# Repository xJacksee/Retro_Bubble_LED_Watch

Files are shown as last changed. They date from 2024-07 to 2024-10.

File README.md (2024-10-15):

# Retro Bubble LED Watch
Retro Bubble LED Watch is a project dedicated to infamous HP's bubble LED seven segment displays produced around 1970s. The goal of this project is to create fully functional retro watch from scratch (including code) based around modern components while the aforementioned display being the centerpiece.

## Project's goal
Retro Bubble LED Watch is a project dedicated to infamus HP's bubble LED seven segment displays produced around 1970s. The goal of this project is to create fully functional retro watch from scratch (including code) based around modern components while the afordmentioned display being the centerpiece.

## Components
The circuit features ATMega328PB microcontroller fulfilling the role as the display multiplexer and I2C communicator with RTC module. For the RTC IC a popular DS1337 has been chosen due it's low standby power, wide supplay voltage range and low price point. Along with this IC comes an external precision quartz crystal designed for digital watches. Due to space limitations a standard 3V CR2032 lithium coin battery supplies power to the circuit. The capacity as well as the footprint of this power source is quite large and thus the rough estimated lifetime of single cell might be as long as 2,5 years while normal use.

## Features
- Display time with precision to tenths of seconds
- Date and numbered day of the week (1 - monday etc.) display
- Temperature measurement by uC's built-in sensor (requires individual calibration)
- 2 independent alarms
- Optional external buzzer activated on alarm trigger
- SPI pins accesable for easy reprogramming
- 2 buttons for activating display/changing modes and time/date/alarm setting

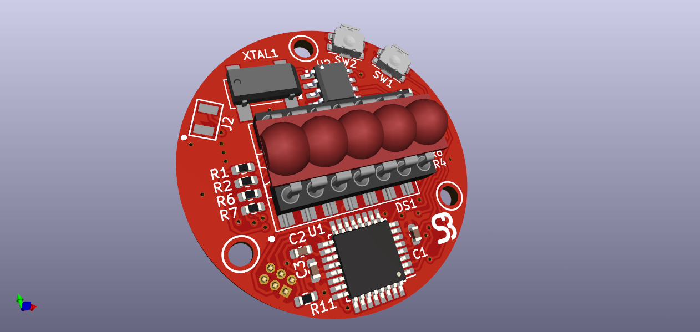
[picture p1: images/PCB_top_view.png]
PCB Top View

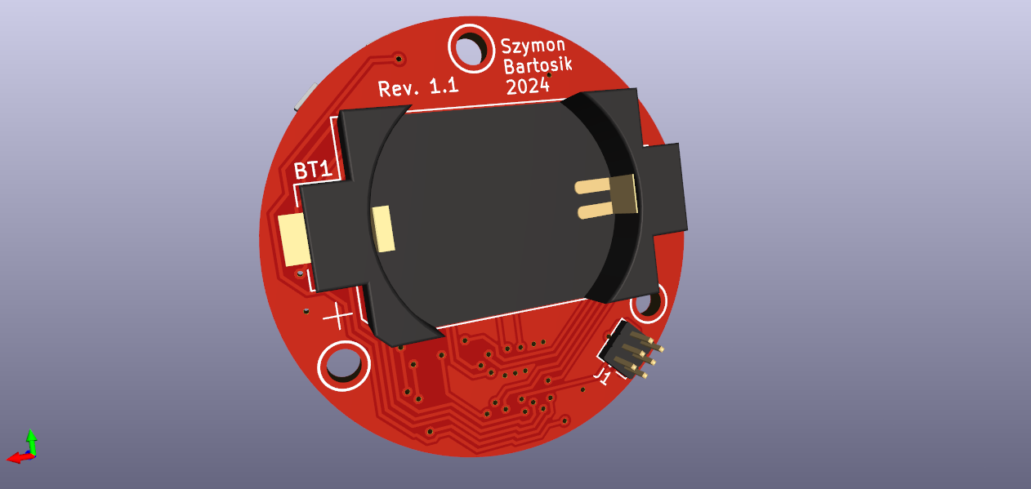
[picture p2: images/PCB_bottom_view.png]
PCB Bottom View


## Dependencies
The programme has been written in Arduino using only Wire library. To upload the code it is nessesary to install and add Mini-Core library to Arduino IDE. The fuse bits settings for ATmega328PB have to be left at factory default (including clock - internal 8MHz RC colock have been used) according to official Microchip datasheet.

## Temperature sensor calibration
Please refer to to ATmega328PB's datasheet section 28.8. "Temperature Measurement" or AVR122 application note. Every MCU requires individual calibration. In this project, a single point calibration method was used. The offset value can be tuned in source code by changing the value of "T_OFFSET" definition.

## External buzzer
Due to space limitations, an alarm buzzer couldn't be fitted on the PCB. Solder pads J2 provide a connection to the PE0 pin of MCU that turns on periodacly during the alarm. External piezoelectric disc can be connected to these pads and fitted onto the internal surface of the lid. The buzzer must not consume more than 40mA otherwise MCU can be damaged. 

## Case
The case is designed to be 3D printed using any material. Supports are nessesary.

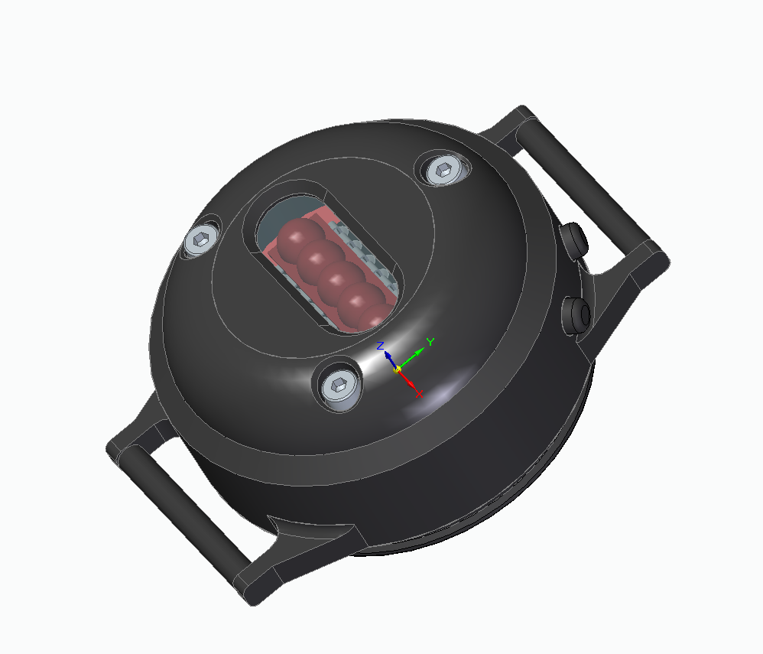
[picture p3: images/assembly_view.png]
Assembly

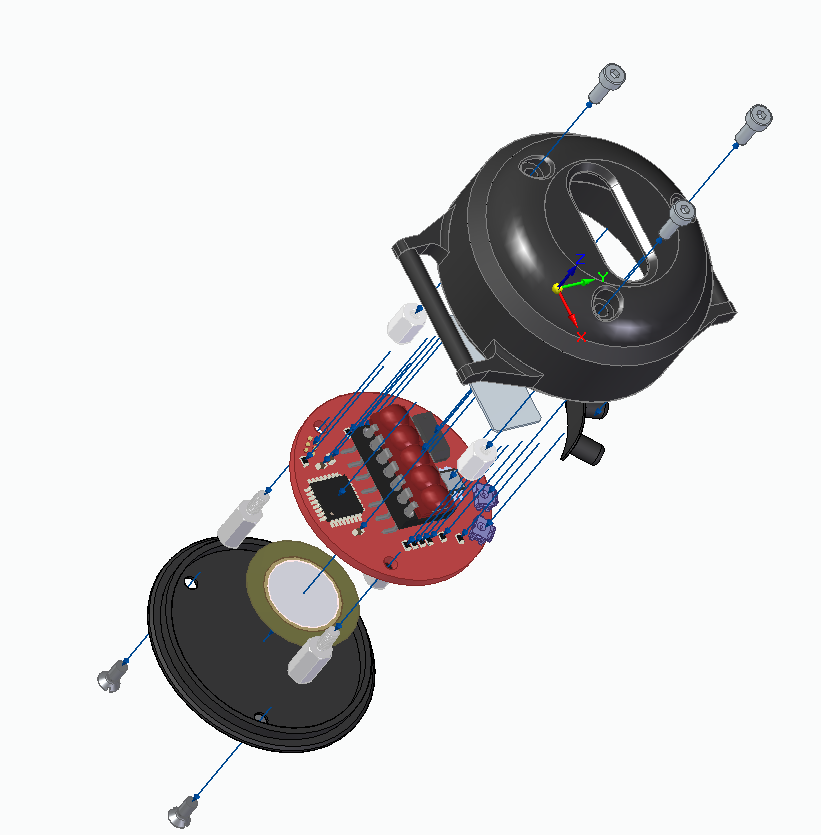
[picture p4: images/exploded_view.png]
Exploded View


## Battery life and current consumption
The CR2032 battery has the capacity to power the circuit for over 2 years but the accurate battery life is dependant on frequency of turing on the display which can consume up to 35mA in peak. This loads the battery and the voltage drop can couse the uC to shutdown when battery is drained. While in sleep the circuit consumes, according to manufacturers' datasheets maximum of arund 5uA in worst case scenario.

## Authors
Szymon Bartosik

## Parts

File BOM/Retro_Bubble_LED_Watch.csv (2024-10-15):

Source: | C:\Users\Szymon\Documents\Projects_Repository\Retro_Bubble_LED_Watch\kicad\Retro_Bubble_LED_Watch\Retro_Bubble_LED_Watch.kicad_sch
Date: | 15/10/2024 12:57:53
Tool: | Eeschema 7.0.10
Generator: | C:\Program Files\KiCad\7.0\bin\scripting\plugins/bom_csv_grouped_by_value.py
Component Count: | 23
Collated Components:
Item | Qty | Reference(s) | Value | LibPart | Footprint | Datasheet | DNP | Manufacturer | Model | Socket | Socket
1 | 1 | BT1 | 3V | Device:Battery_Cell | Battery:BatteryHolder_Keystone_1060_1x2032 | ~ |  | PANASONIC | CR2032/BN |  | KEYSTONE 1060
2 | 3 | C1, C2, C3 | 100n | Device:C | Capacitor_SMD:C_0603_1608Metric | ~ |  | SAMSUNG | CL10B104KA8NFNC
3 | 1 | DS1 | 5082-7415 | 5082-7415:5082-7415 | Package_DIP:DIP-14_W8.89mm_SMDSocket_LongPads |  |  | HP |  | CONNFLY DS1001-02-14N13
4 | 1 | J1 | 20021111-00006T4LF | Connector_Generic:Conn_02x03_Counter_Clockwise | Connector_PinHeader_1.27mm:PinHeader_2x03_P1.27mm_Vertical | ~ |  | AMPHENOL COMMUNICATIONS SOLUTIONS
5 | 1 | J2 | Pad Connector | Connector_Generic:Conn_01x02 | footprints:Pad_Conn_2x1_2x1mm_2.54mm | ~
6 | 8 | R1, R2, R3, R4, R5, R6, R7, R8 | 330R | Device:R | Resistor_SMD:R_0603_1608Metric | ~ |  | PANASONIC | ERJ3EKF3300V
7 | 3 | R9, R10, R11 | 10k | Device:R | Resistor_SMD:R_0603_1608Metric | ~ |  | PANASONIC | ERJ3EKF1002V
8 | 2 | SW1, SW2 | KMS231G | Switch:SW_Push | Button_Switch_SMD:SW_SPST_CK_KMS2xxG | ~ |  | C&K | KMS231GLFS
9 | 1 | U1 | ATmega328PB-A | MCU_Microchip_ATmega:ATmega328PB-A | Package_QFP:TQFP-32_7x7mm_P0.8mm | http://ww1.microchip.com/downloads/en/DeviceDoc/40001906C.pdf |  | MICROCHIP
10 | 1 | U2 | DS1337S+ | DS1337S+:DS1337S+ | footprints:SOIC127P600X175-8N |  |  | MAXIM INTEGRATED
11 | 1 | XTAL1 | LFXTAL016178Reel | LFXTAL016178Reel:LFXTAL016178Reel | footprints:LFXTAL016178Reel |  |  | IQD FREQUENCY PRODUCTS

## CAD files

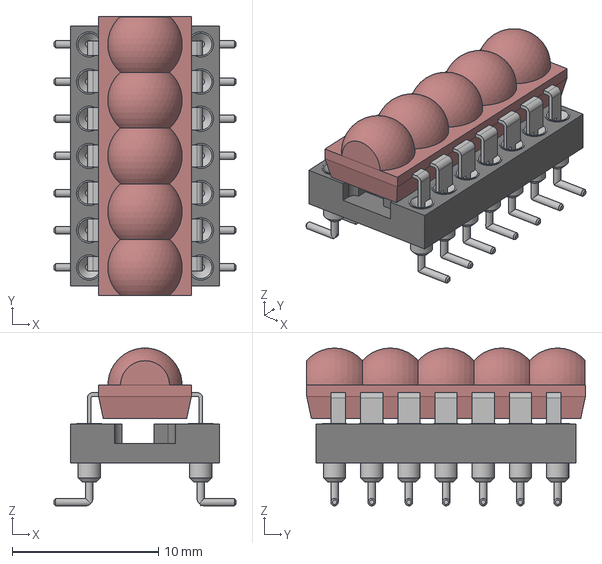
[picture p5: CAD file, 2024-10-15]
models/step/HP5082-7415_with_SMD_Socket_assembly.stp
12.4 x 19.1 x 10.8 mm

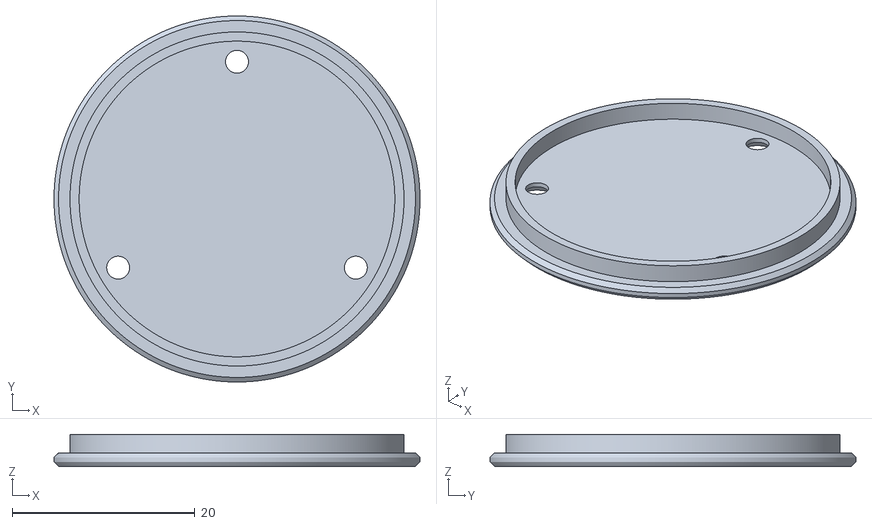
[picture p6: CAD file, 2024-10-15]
models/stl/lid.stl
40.0 x 40.0 x 3.50

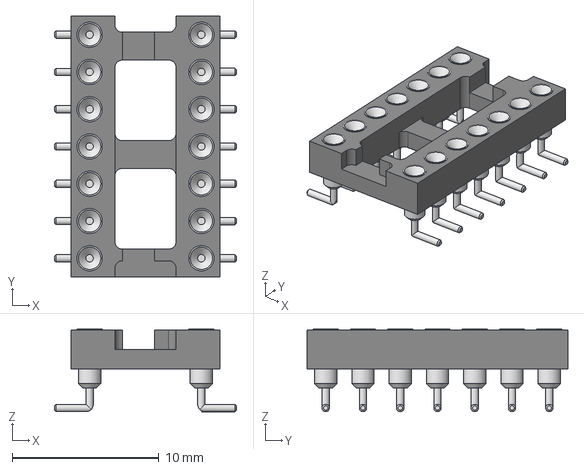
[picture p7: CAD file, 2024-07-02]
models/step/DIP-14_W7.62mm_SMD_Socket.stp
12.4 x 17.8 x 5.63 mm

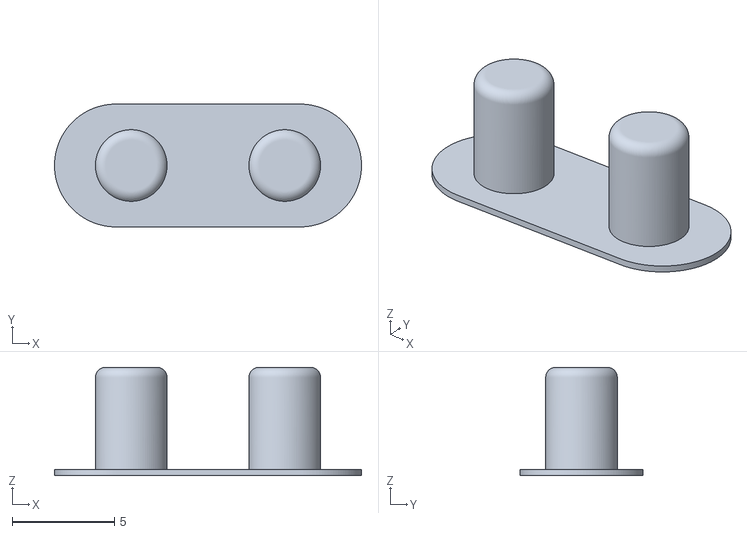
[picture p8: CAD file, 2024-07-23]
models/stl/buttons.stl
15.0 x 6.00 x 5.30

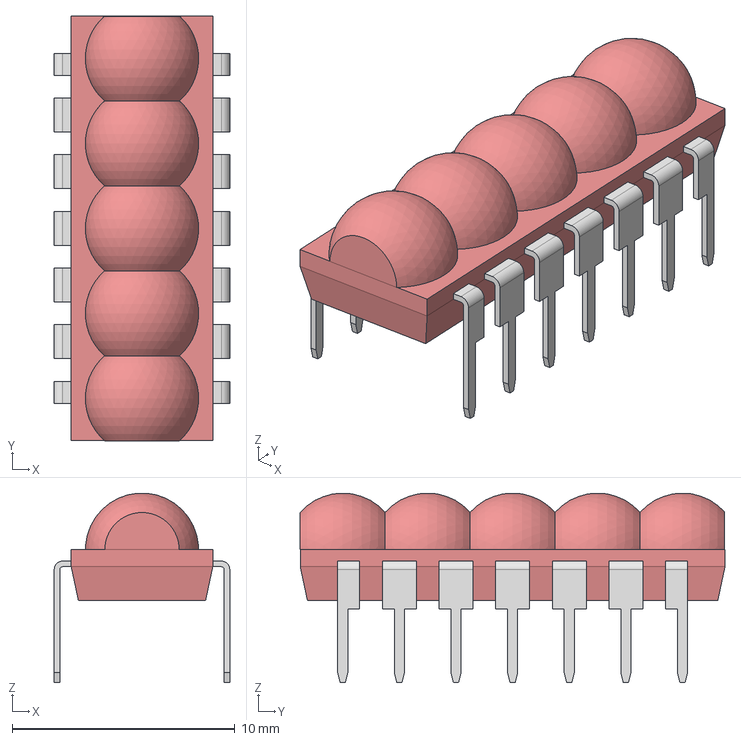
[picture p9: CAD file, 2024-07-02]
models/step/HP5082-7415.stp
7.87 x 19.1 x 8.50 mm

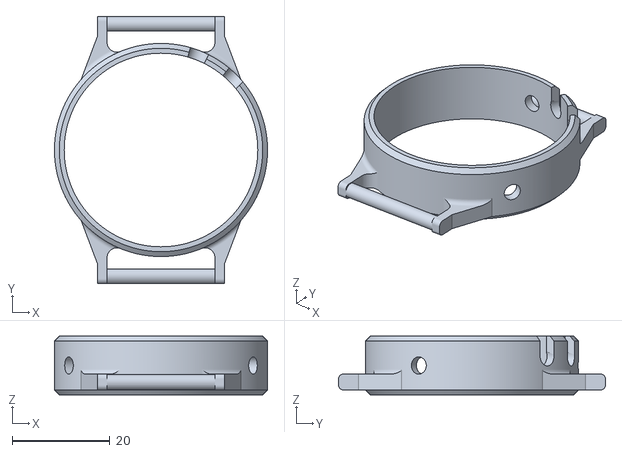
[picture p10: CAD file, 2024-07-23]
models/stl/strap_holder.stl
43.5 x 54.5 x 12.0

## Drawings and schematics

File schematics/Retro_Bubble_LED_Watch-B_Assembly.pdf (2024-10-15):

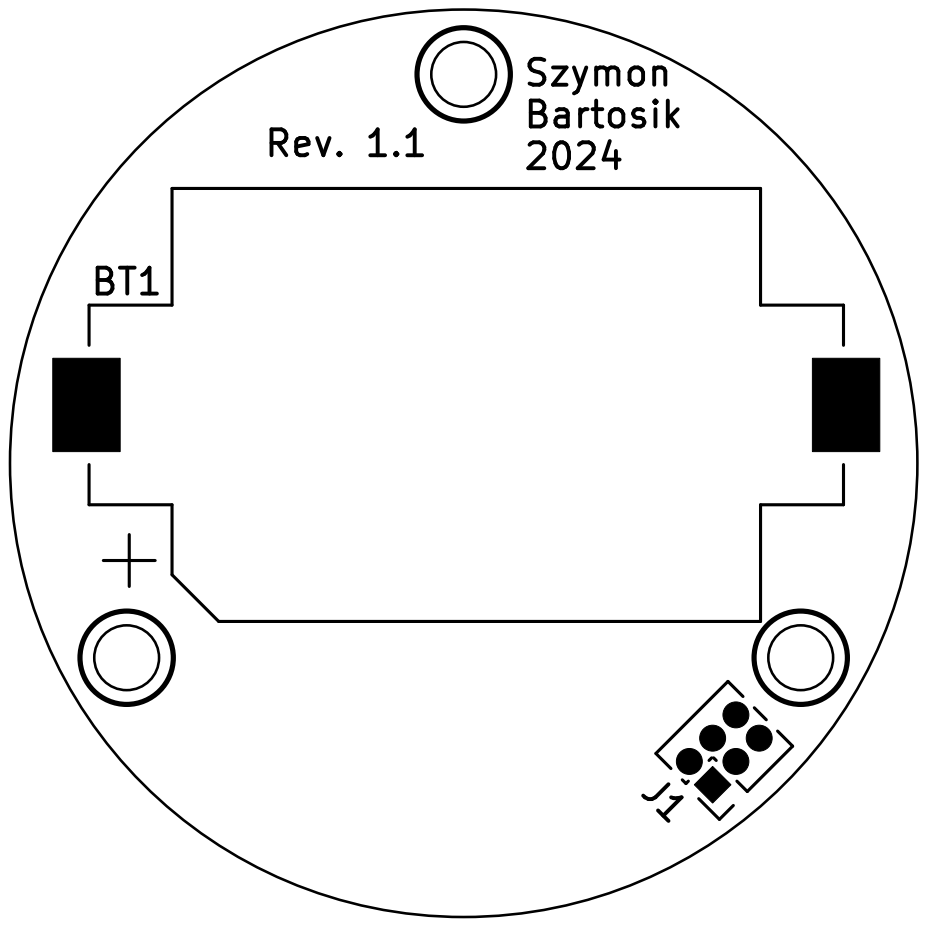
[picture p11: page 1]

Id: 1/1 Title: Retro Bubble LED Watch

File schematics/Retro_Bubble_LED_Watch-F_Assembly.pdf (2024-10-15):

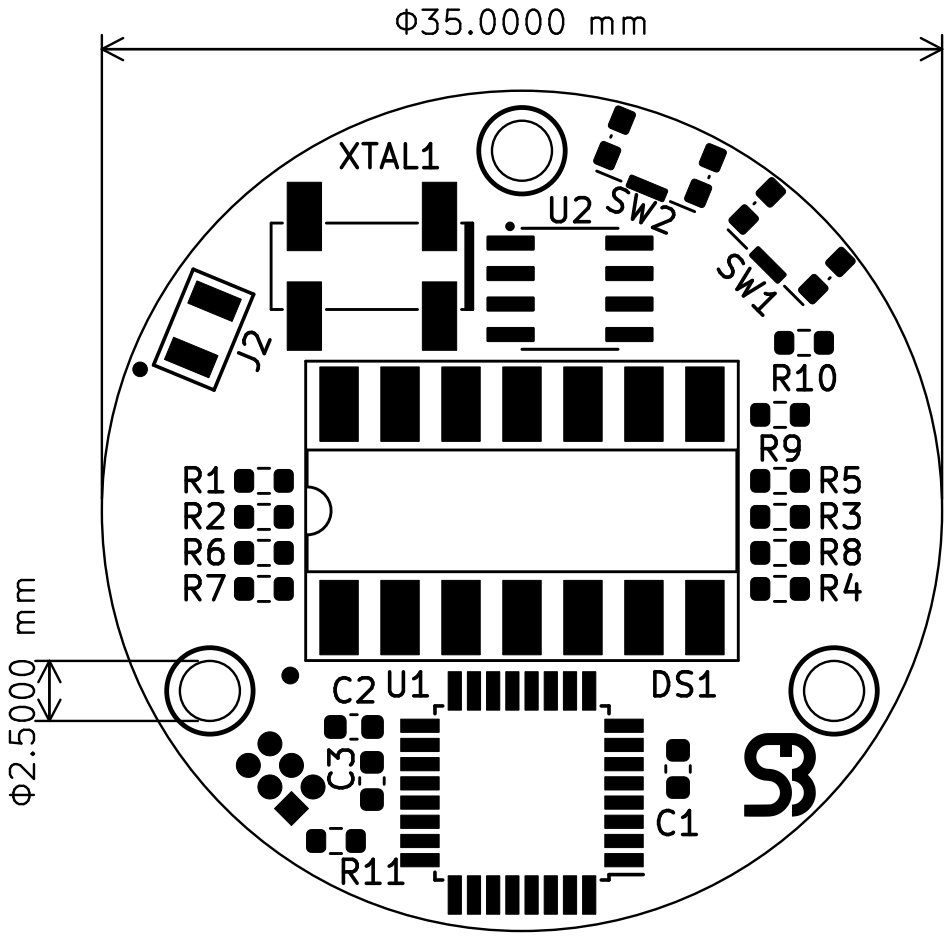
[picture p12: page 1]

Id: 1/1 Title: Retro Bubble LED Watch

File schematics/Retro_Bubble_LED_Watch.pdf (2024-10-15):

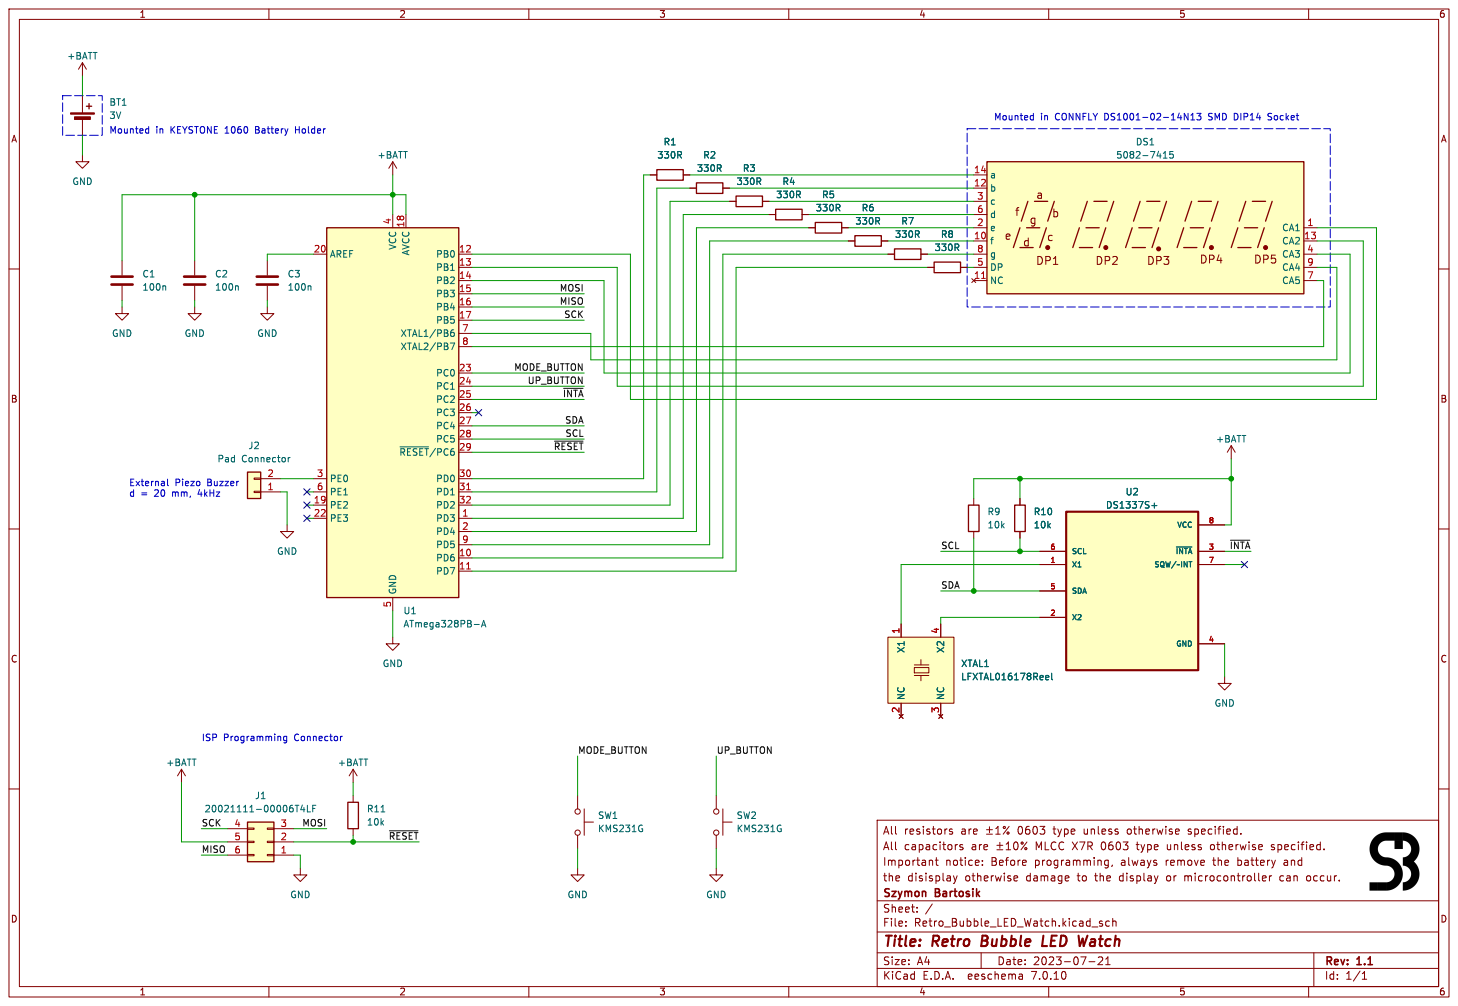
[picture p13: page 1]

Id: 1/1 Title: Retro Bubble LED Watch

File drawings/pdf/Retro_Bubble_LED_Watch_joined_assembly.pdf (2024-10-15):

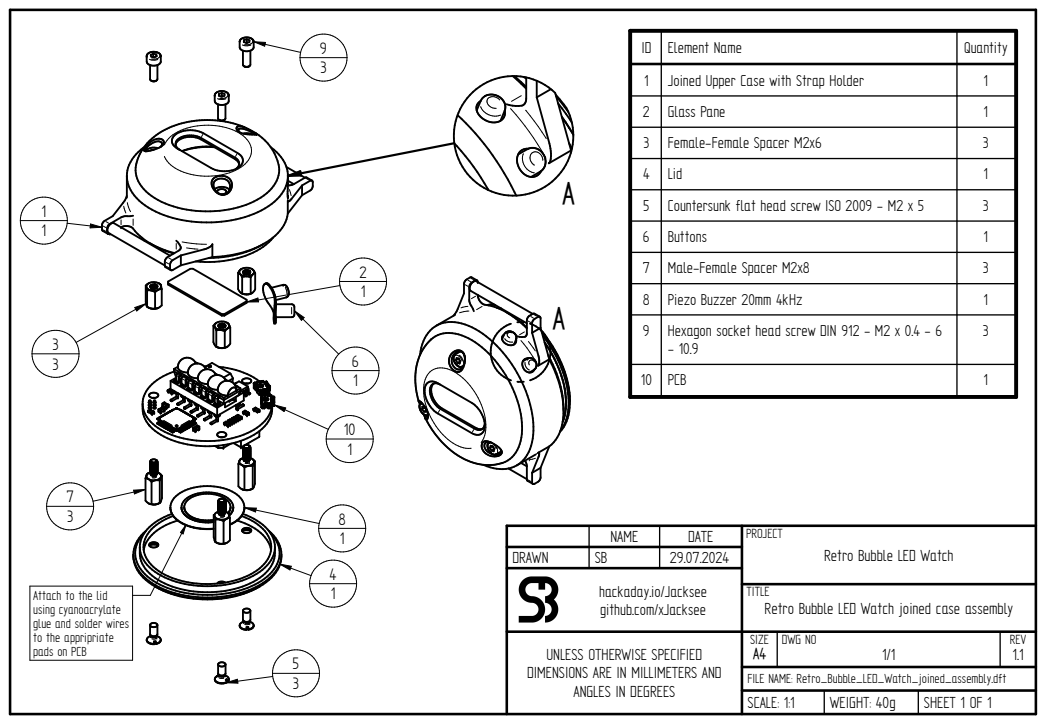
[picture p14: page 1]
SIZE A4; DWG NO; REV 1.1; FILE NAME: Retro_Bubble_LED_Watch_joined_assembly.dft; SCALE: 1:1; WEIGHT: 40g; SHEET 1 OF 1; ID Element Name; Quantity; 1 Joined Upper Case with Strap Holder; 2 Glass Pane; 3 Female-Female Spacer M2x6; 4 Lid; 5 Countersunk flat head screw ISO 2009 - M2 x 5; 6 Buttons; 7 Male-Female Spacer M2x8; 8 Piezo Buzzer 20mm 4kHz; 10 PCB

9 Hexagon socket head screw DIN 912 - M2 x 0.4 - 6

NAME | DATE | PROJECT Retro Bubble LED Watch

DRAWN | SB | 29.07.2024

hackaday.io/Jacksee
github.com/xJacksee

TITLE
Retro Bubble LED Watch joined case assembly

Attach to the lid
using cyanoacrylate
glue and solder wires
to the appripriate
pads on PCB

UNLESS OTHERWISE SPECIFIED
DIMENSIONS ARE IN MILLIMETERS AND
ANGLES IN DEGREES

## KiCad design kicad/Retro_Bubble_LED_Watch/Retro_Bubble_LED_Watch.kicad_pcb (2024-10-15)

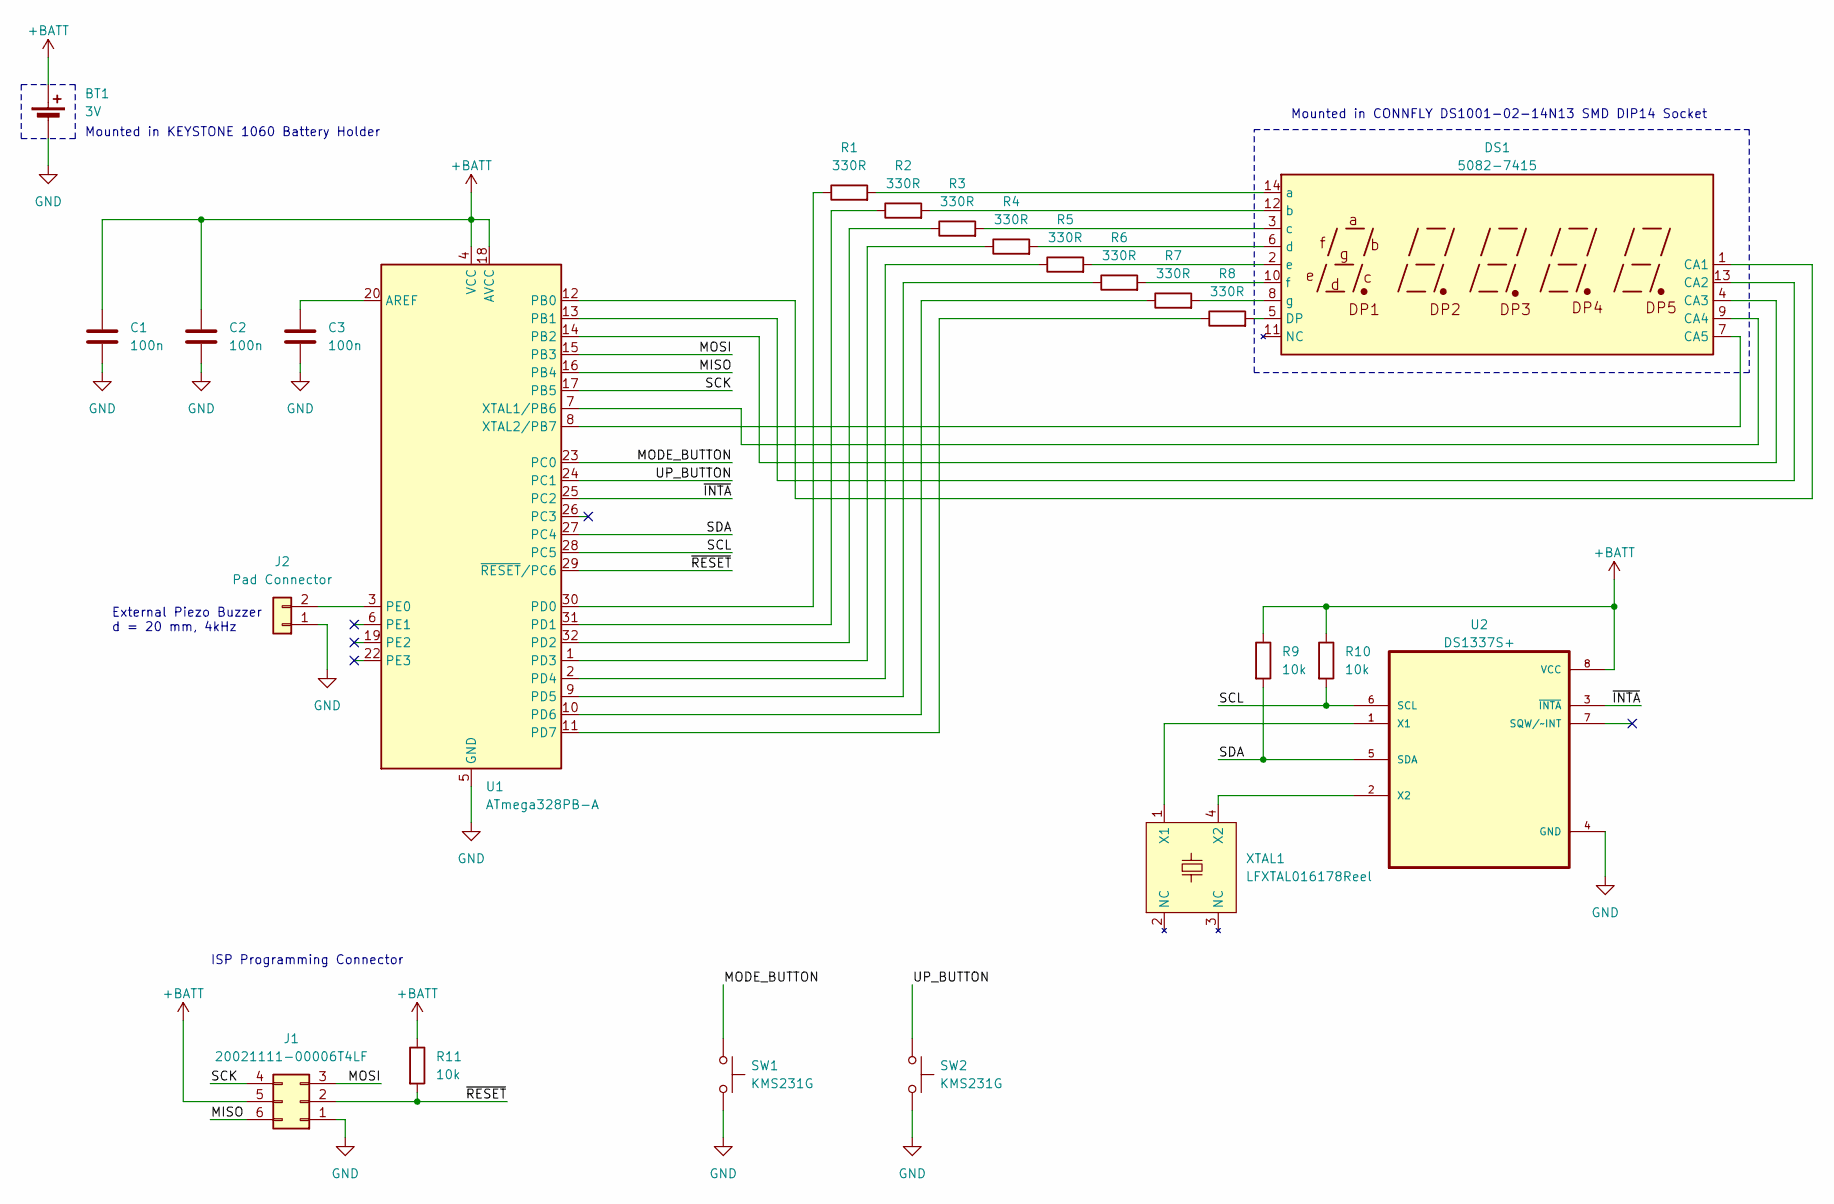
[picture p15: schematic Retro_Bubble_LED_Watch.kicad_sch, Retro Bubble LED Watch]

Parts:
BT1: 3V; BatteryHolder_Keystone_1060_1x2032
C1, C2, C3: 100n; C_0603_1608Metric
DS1: 5082-7415; DIP-14_W8.89mm_SMDSocket_LongPads
J1: 20021111-00006T4LF; PinHeader_2x03_P1.27mm_Vertical
J2: Pad Connector; Pad_Conn_2x1_2x1mm_2.54mm
R1, R2, R3, R4, R5, R6, R7, R8: 330R; R_0603_1608Metric
R9, R10, R11: 10k; R_0603_1608Metric
SW1, SW2: KMS231G; SW_SPST_CK_KMS2xxG
U1: ATmega328PB-A; TQFP-32_7x7mm_P0.8mm
U2: DS1337S+; SOIC127P600X175-8N
XTAL1: LFXTAL016178Reel

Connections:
+BATT: BT1.1 (+), C1.1, C2.1, J1.5, R9.1, R10.1, R11.1, U1.4 (VCC), U1.18 (AVCC), U2.8 (VCC)
/MISO: J1.6, U1.16 (PB4)
/MODE_BUTTON: SW1.1, U1.23 (PC0)
/MOSI: J1.3, U1.15 (PB3)
/SCK: J1.4, U1.17 (PB5)
/SCL: R10.2, U1.28 (PC5), U2.6 (SCL)
/SDA: R9.2, U1.27 (PC4), U2.5 (SDA)
/UP_BUTTON: SW2.1, U1.24 (PC1)
/~INTA: U1.25 (PC2), U2.3 (~INTA)
/~RESET: J1.2, R11.2, U1.29 (~RESET/PC6)
GND: BT1.2 (-), C1.2, C2.2, C3.2, J1.1, J2.1, SW1.2, SW2.2, U1.5 (GND), U1.21 (GND), U2.4 (GND)
unnamed: DS1.1 (CA1), U1.12 (PB0)
unnamed: DS1.13 (CA2), U1.13 (PB1)
unnamed: DS1.4 (CA3), U1.14 (PB2)
unnamed: DS1.9 (CA4), U1.7 (XTAL1/PB6)
unnamed: DS1.7 (CA5), U1.8 (XTAL2/PB7)
unnamed: DS1.5 (DP), R8.2
unnamed: DS1.14 (a), R1.2
unnamed: DS1.12 (b), R2.2
unnamed: DS1.3 (c), R3.2
unnamed: DS1.6 (d), R4.2
unnamed: DS1.2 (e), R5.2
unnamed: DS1.10 (f), R6.2
unnamed: DS1.8 (g), R7.2
unnamed: J2.2, U1.3 (PE0)
unnamed: C3.1, U1.20 (AREF)
unnamed: R1.1, U1.30 (PD0)
unnamed: R2.1, U1.31 (PD1)
unnamed: R3.1, U1.32 (PD2)
unnamed: R4.1, U1.1 (PD3)
unnamed: R5.1, U1.2 (PD4)
unnamed: R6.1, U1.9 (PD5)
unnamed: R7.1, U1.10 (PD6)
unnamed: R8.1, U1.11 (PD7)
unnamed: U2.1 (X1), XTAL1.1 (X1)
unnamed: U2.2 (X2), XTAL1.4 (X2)

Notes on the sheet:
Mounted in CONNFLY DS1001-02-14N13 SMD DIP14 Socket
External Piezo Buzzer d = 20 mm, 4kHz
ISP Programming Connector
Mounted in KEYSTONE 1060 Battery Holder

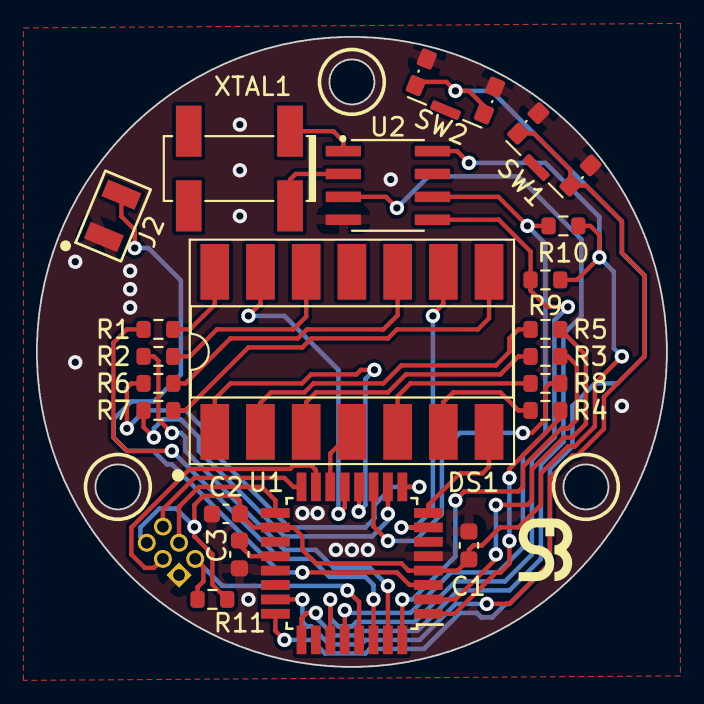
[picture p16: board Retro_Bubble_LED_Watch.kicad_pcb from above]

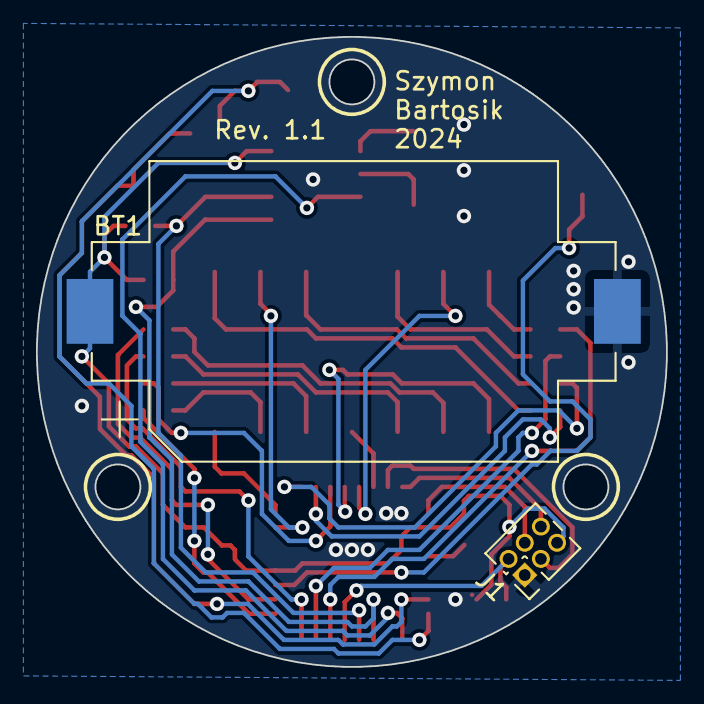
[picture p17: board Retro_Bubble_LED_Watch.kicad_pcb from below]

Board: 2 copper layers, 35.0 x 35.0 mm, 23 parts (2 on the bottom side), 36 nets.

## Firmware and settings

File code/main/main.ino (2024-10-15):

/*
***************************
* Retro Bubble LED Watch  *
* Revision: 1.1           *
* Version: 1.2            *
* Date: 15.09.2024        *
* Szymon Bartosik         *
***************************

Description:

Arduino Core: https://github.com/MCUdude/MiniCore
Bootloader: None
BOD: Disabled
Clock: Internal RC clock at 1MHz (factory default)
All other fuse/lock bits are set to factory defalult as stated in datasheet

Wiring:

Segments:
PD0 - a
PD1 - b
PD2 - c
PD3 - d
PD4 - e
PD5 - f
PD6 - g
PD7 - dp

Cathodes:
PB0 - CA1 - position 0
PB1 - CA2 - position 1
PB2 - CA3 - position 2
PB6 - CA4 - position 3
PB7 - CA5 - position 4

RTC I2C communication:
PC5 - SCL
PC4 - SDA

Buttons:
PC0 - MODE switch
PC1 - UP switch

RTC interrupts:
PC2 - RTC alarm interrupt

External components:
PE0 - 20mm 4kHz piezo disc


*/
#include <Arduino.h>
#include <Wire.h> //Library needed for I2C communication with RTC module

//Number of display's digits
#define DIGITS_COUNT    5

//DS1337 RTC register addresses
#define RTC_ADDR        0x68
#define SEC_ADDR        0x00
#define MIN_ADDR        0x01
#define HOUR_ADDR       0x02
#define DAY_ADDR        0x03
#define DATE_ADDR       0x04
#define MONTH_ADDR      0x05
#define YEAR_ADDR       0x06
#define AL1_SEC_ADDR    0x07
#define AL1_MIN_ADDR    0x08
#define AL1_HOUR_ADDR   0x09
#define AL1_DATE_ADDR   0x0A
#define AL2_MIN_ADDR    0x0B
#define AL2_HOUR_ADDR   0x0C
#define AL2_DATE_ADDR   0x0D
#define CTRL_ADDR       0x0E
#define STATUS_ADDR     0x0F

//Temperature sensor calibrated offset at room temperature (has to be calibrated for each chip indivudually; use this value as a reference)
#define T_OFFSET        280

//Function prototypes
int temp_read();
uint8_t rtc_read(uint8_t);
uint8_t rtc_read_dec(uint8_t);
uint8_t read_digit(uint8_t, bool);
bool bit_read(uint8_t, uint8_t);
void rtc_write(uint8_t, uint8_t);
void display_write();

//Menu list
enum menu_list {
  READ_TIME,
  READ_DATE,
  READ_YEAR,
  READ_TEMP,
  READ_ALARM1,
  READ_ALARM1_STATUS,
  READ_ALARM2,
  READ_ALARM2_STATUS,
  WRITE_HOUR,
  WRITE_MINUTE,
  WRITE_SECOND,
  WRITE_DAY,
  WRITE_DATE,
  WRITE_MONTH,
  WRITE_YEAR,
  WRITE_ALARM1_HOUR,
  WRITE_ALARM1_MINUTE,
  WRITE_ALARM1_SECOND,
  WRITE_ALARM1_STATUS,
  WRITE_ALARM2_HOUR,
  WRITE_ALARM2_MINUTE,
  WRITE_ALARM2_STATUS,
  ALARM_TRIGGER
};

//Menu display structure definition
typedef struct Display {
  bool dots[DIGITS_COUNT];
  uint8_t digits[DIGITS_COUNT];
  } display;

//Menu display structures with default (blank) values
display read_time = {{0,1,0,1,0}, {10, 10, 10, 10, 10}};
display read_date = {{1,0,1,0,1}, {10, 10, 10, 10, 10}};
display read_year = {{0,0,0,0,0}, {2, 0, 10, 10, 10}};
display read_alarm1 = {{0,1,0,1,0}, {10, 10, 10, 10, 10}};
display read_alarm1_status = {{0,0,0,0,0}, {10,10,11,13,13}};
display read_alarm2 = {{0,1,0,1,0}, {10, 10, 10, 10, 0}};
display read_alarm2_status = {{0,0,0,0,0}, {10,10,11,13,13}};
display read_temp = {{0,0,0,0,0}, {10,10,10,14,16}};

//Current position for display
uint8_t position = 0;
//Curret menu selected by user
volatile enum menu_list menu = READ_TIME;
//Write/read mode flag
volatile bool write_mode = 0;
//Digit up write value
volatile uint8_t up = 0;
//Blink period (ms)
const uint8_t t_blink = 450;
//Sleep mode flag
volatile bool sleep_flag = 0;
//Temperature reading
int T = 0;

//Menu structure pointer array
const display* display_ptr[] = {&read_time, &read_date, &read_year, &read_temp, &read_alarm1, &read_alarm1_status, &read_alarm2, &read_alarm2_status, &read_time, &read_time, &read_time, &read_date, &read_date, &read_date, &read_year, &read_alarm1, &read_alarm1, &read_alarm1, &read_alarm1_status, &read_alarm2, &read_alarm2, &read_alarm2_status, &read_time};
//Position lookup table for PORT manipulation
const uint8_t position_array[] = {0b11111110, 0b11111101, 0b11111011, 0b10111111, 0b01111111};  //CA1,CA2,CA3,CA4,CA5
//Digit segment configuration for PORT manipulation
const uint8_t digits_array[] = {0b00111111, 0b00000110, 0b01011011, 0b01001111, 0b01100110, 0b01101101, 0b01111101, 0b00000111, 0b01111111, 0b01101111, 0b00000000, 0b01011100, 0b00110111, 0b01110001, 0b01100011, 0b01000000, 0b00111001};  //0,1,2,3,4,5,6,7,8,9,null,o,n,f,deg,-,C

//Interrupt service routine for Timer 1 to regularly update display
ISR(TIMER1_COMPA_vect) {
  if (!sleep_flag) {
    display_write();
  }
}

//Interrupt service routine for toggling write mode if MODE button was pressed for set time
ISR(TIMER3_COMPA_vect) {
  TCCR3B = 0b00000000;  //Stop Timer 3
  TCNT3 = 0;            //Set Timer 3 value to 0
  write_mode = 1;       //Enable write mode flag
  menu = WRITE_HOUR;    //Go to first write menu
}

//Interrupt service routine for MODE and UP switches + alarm
ISR(PCINT1_vect) {
  TCNT4 = 0;                    //Reset sleep timer
  if (sleep_flag) {
    TCCR1B  = 0b00001001; //Enable display refreshing timer
    menu = READ_TIME;     //Let the first menu to display after wake-up to be READ_TIME
  }
  if (!(PINC & 0b00000100)) { //If alarm was triggered
    menu = ALARM_TRIGGER;
  }
  else if (!(PINC & 0b00000001)) { //If MODE button was pressed (detect LOW state)
    TCCR3B = 0b00000011;      //Start Timer 3 with 64 prescaler
    if (!sleep_flag) {
      menu = menu + 1;          //Cycle through menus
    }
    if (menu > READ_ALARM2_STATUS & !write_mode) {
      menu = READ_TIME;
    }
    else if (menu > WRITE_ALARM2_STATUS & write_mode){
      menu = READ_TIME;
      write_mode = 0;
    }
  }
  else if (!(PINC & 0b00000010) & write_mode & (menu != ALARM_TRIGGER)) { //If UP button was pressed (detect LOW state)
    up++; //Increment digit
  }
  else if (PINC & 0b00000001){ //If MODE button was depressed (detect HIGH state)
    TCCR3B = 0b00000000;  //Stop Timer 3
    TCNT3 = 0;            //Set Timer 3 value to 0
  }
  PORTE = 0b00000000;
  sleep_flag = 0;               //Disable sleep
}

//Interrupt service routine for entering sleep mode
ISR(TIMER4_COMPA_vect) {
  sleep_flag = 1;
}

void setup() {
  //Set sleep mode register to Power-down mode and enable it
  SMCR = 0b00000101;
  
  //Set Timer 1 to interrupt and refresh screen periodacly
  TCCR1A  = 0b00000000; //No PWM functions
  TCNT1   = 0;          //Reset initial value
  TCCR1B  = 0b00001001; //No prescaler, CTC for OCR1A
  TIMSK1  = 0b00000010; //Set interrupt on compare A
  OCR1A   = 1000;       //Display new digit every 5ms
  
  //Set Timer 3 to count how long MODE button was pressed
  TCCR3A = 0b00000000;  //No PWM functions
  TCCR3B = 0b00000000;  //Keep Timer 3 initially disabled
  TCNT3 = 0;            //Reset initial value
  TIMSK3 = 0b00000010;  //Set interrupt on compare A
  OCR3A = 31250;        //Set 2s write mode trigger time (64 prescaler set in ISR)

  //Set Timer 4 to countdown time to enter sleep mode
  TCCR4A = 0b00000000;  //No PWM functions
  TCNT4 = 0;            //Reset initial value
  TCCR4B = 0b00001011;  //Enable Timer 4 with 64 prescaler and CTC for OCR4A
  TIMSK4 = 0b00000010;  //Set interrupt on compare A
  OCR4A = 62500;        //Set 4s time to display before enabling power-down sleep
  
  //Set D and B pins as outputs for driving the display
  DDRD = 0b11111111;
  DDRB = 0b11000111;
  
  //Set C pins as inputs for switches and enable pullup resistors
  DDRC &= 0b11110000;
  PORTC |= 0b00000111;

  //Set pin in E port as an output for buzzer alarm
  DDRE  = 0b00000001;
  PORTE = 0b11111110;

  //Setup ADC to measure internal temperature
  ADMUX   = 0b11001000;  //Internal 1.1V reference and temperature sensor selected
  
  //Initialize Pin Chnage Interrupts
  PCICR |= 0b00000010;  //Enable PCI for bank C
  PCIFR |= 0b00000111;  //Clear interrupt flags
  PCMSK1 |= 0b00000111; //Enable PCI for PC0, PC1 and PC2
  
  //Initialize I2C communication library
  Wire.begin();
  
  //Set alrms to trigger when only time matches
  rtc_write(AL1_DATE_ADDR, 0b10000001); 
  rtc_write(AL2_DATE_ADDR, 0b10000001);

  //Disable alarms by default and set ~INTA as only alarm pin (these are default values of RTC's register but have to be setup this way due to possible random changes after programming and startup)
  rtc_write(CTRL_ADDR, 0b00000000);
  
  //Clear alaram flags
  rtc_write(STATUS_ADDR, 0b00000000);
  
  //Enable external interrupts
  sei();
}

void loop() {
  if (sleep_flag) {
    PORTE = 0b11111110;   //Pull buzzer pin low
    ADCSRA  = 0b00000011; //Disable ADC
    PORTD =  0b00000000;  //Disable all LED segments
    PORTB =  0b00111000;  //Set cathodes to ground
    sleep_mode();         //Enter sleep
  }
  
  switch(menu) {
    
    case READ_TIME:
      read_time.digits[0] = read_digit(HOUR_ADDR,1);
      read_time.digits[1] = read_digit(HOUR_ADDR,0);
      read_time.digits[2] = read_digit(MIN_ADDR,1);
      read_time.digits[3] = read_digit(MIN_ADDR,0);
      read_time.digits[4] = read_digit(SEC_ADDR,1);
    break;
      
    case READ_DATE:
      read_date.digits[0] = read_digit(DAY_ADDR,0);
      read_date.digits[1] = read_digit(DATE_ADDR,1);
      read_date.digits[2] = read_digit(DATE_ADDR,0);
      read_date.digits[3] = read_digit(MONTH_ADDR,1);
      read_date.digits[4] = read_digit(MONTH_ADDR,0);
    break;
      
    case READ_YEAR:
      read_year.digits[2] = read_digit(YEAR_ADDR,1);
      read_year.digits[3] = read_digit(YEAR_ADDR,0);
    break;

    case READ_TEMP:
      T = temp_read();
      if (T < 0)  {
        read_temp.digits[0] = 15; //Write -
      }
      else {
        read_temp.digits[0] = 10;
      }

      read_temp.digits[1] = (abs(T) - abs(T) % 10) / 10;
      read_temp.digits[2] = abs(T) % 10;
    break;
      
    case READ_ALARM1:
      read_alarm1.digits[0] = read_digit(AL1_HOUR_ADDR,1);
      read_alarm1.digits[1] = read_digit(AL1_HOUR_ADDR,0);
      read_alarm1.digits[2] = read_digit(AL1_MIN_ADDR,1);
      read_alarm1.digits[3] = read_digit(AL1_MIN_ADDR,0);
      read_alarm1.digits[4] = read_digit(AL1_SEC_ADDR,1);
    break;

    case READ_ALARM1_STATUS:
      if (read_bit(CTRL_ADDR, 0)) {
        read_alarm1_status.digits[2] = 10;
        read_alarm1_status.digits[3] = 11;
        read_alarm1_status.digits[4] = 12;
      }
      else {
        read_alarm1_status.digits[2] = 11;
        read_alarm1_status.digits[3] = 13;
        read_alarm1_status.digits[4] = 13;
      }
    break;
    
    case READ_ALARM2:
      read_alarm2.digits[0] = read_digit(AL2_HOUR_ADDR,1);
      read_alarm2.digits[1] = read_digit(AL2_HOUR_ADDR,0);
      read_alarm2.digits[2] = read_digit(AL2_MIN_ADDR,1);
      read_alarm2.digits[3] = read_digit(AL2_MIN_ADDR,0);
    break;
      
    case READ_ALARM2_STATUS:
      if (read_bit(CTRL_ADDR, 1)) {
        read_alarm2_status.digits[2] = 10;
        read_alarm2_status.digits[3] = 11;
        read_alarm2_status.digits[4] = 12;
      }
      else {
        read_alarm2_status.digits[2] = 11;
        read_alarm2_status.digits[3] = 13;
        read_alarm2_status.digits[4] = 13;
      }
    break;

    case WRITE_HOUR:
      read_time.digits[2] = read_digit(MIN_ADDR,1);
      read_time.digits[3] = read_digit(MIN_ADDR,0);
      read_time.digits[4] = read_digit(SEC_ADDR,1);
      if (rtc_read_dec(HOUR_ADDR) + up <= 23) {
        rtc_write(HOUR_ADDR,rtc_read_dec(HOUR_ADDR) + up);
        up = 0;
      }
      else {
        rtc_write(HOUR_ADDR, 0);
        up = 0;
      }
      read_time.digits[0] = read_digit(HOUR_ADDR,1);
      read_time.digits[1] = read_digit(HOUR_ADDR,0);
      delay(t_blink);
      read_time.digits[0] = 10;
      read_time.digits[1] = 10;
      delay(t_blink);
    break;

    case WRITE_MINUTE:
      read_time.digits[0] = read_digit(HOUR_ADDR,1);
      read_time.digits[1] = read_digit(HOUR_ADDR,0);
      read_time.digits[4] = read_digit(SEC_ADDR,1);
      if (rtc_read_dec(MIN_ADDR) + up <= 59) {
        rtc_write(MIN_ADDR,rtc_read_dec(MIN_ADDR) + up);
        up = 0;
      }
      else {
        rtc_write(MIN_ADDR, 0);
        up = 0;
      }
      read_time.digits[2] = read_digit(MIN_ADDR,1);
      read_time.digits[3] = read_digit(MIN_ADDR,0);
      delay(t_blink);
      read_time.digits[2] = 10;
      read_time.digits[3] = 10;
      delay(t_blink);
    break;

    case WRITE_SECOND:
      read_time.digits[0] = read_digit(HOUR_ADDR,1);
      read_time.digits[1] = read_digit(HOUR_ADDR,0);
      read_time.digits[2] = read_digit(MIN_ADDR,1);
      read_time.digits[3] = read_digit(MIN_ADDR,0);
      if (rtc_read_dec(SEC_ADDR) + up*10 <= 59) {
        rtc_write(SEC_ADDR,rtc_read_dec(SEC_ADDR) + up*10);
        up = 0;
      }
      else {
        rtc_write(SEC_ADDR, 0);
        up = 0;
      }
      read_time.digits[4] = read_digit(SEC_ADDR,1);
      delay(t_blink);
      read_time.digits[4] = 10;
      delay(t_blink);
    break;

    case WRITE_DAY:
      read_date.digits[1] = read_digit(DATE_ADDR,1);
      read_date.digits[2] = read_digit(DATE_ADDR,0);
      read_date.digits[3] = read_digit(MONTH_ADDR,1);
      read_date.digits[4] = read_digit(MONTH_ADDR,0);
      if (rtc_read_dec(DAY_ADDR) + up <= 7) {
        rtc_write(DAY_ADDR,rtc_read_dec(DAY_ADDR) + up);
        up = 0;
      }
      else {
        rtc_write(DAY_ADDR, 1);
        up = 0;
      }
      read_date.digits[0] = read_digit(DAY_ADDR,0);
      delay(t_blink);
      read_date.digits[0] = 10;
      delay(t_blink);
    break;

    case WRITE_DATE:
      read_date.digits[0] = read_digit(DAY_ADDR,0);
      read_date.digits[3] = read_digit(MONTH_ADDR,1);
      read_date.digits[4] = read_digit(MONTH_ADDR,0);
      if (rtc_read_dec(DATE_ADDR) + up <= 31) {
        rtc_write(DATE_ADDR,rtc_read_dec(DATE_ADDR) + up);
        up = 0;
      }
      else {
        rtc_write(DATE_ADDR, 1);
        up = 0;
      }
      read_date.digits[1] = read_digit(DATE_ADDR,1);
      read_date.digits[2] = read_digit(DATE_ADDR,0);
      delay(t_blink);
      read_date.digits[1] = 10;
      read_date.digits[2] = 10;
      delay(t_blink);
    break;

    case WRITE_MONTH:
      read_date.digits[0] = read_digit(DAY_ADDR,0);
      read_date.digits[1] = read_digit(DATE_ADDR,1);
      read_date.digits[2] = read_digit(DATE_ADDR,0);
      if (rtc_read_dec(MONTH_ADDR) + up <= 12) {
        rtc_write(MONTH_ADDR,rtc_read_dec(MONTH_ADDR) + up);
        up = 0;
      }
      else {
        rtc_write(MONTH_ADDR, 1);
        up = 0;
      }
      read_date.digits[3] = read_digit(MONTH_ADDR,1);
      read_date.digits[4] = read_digit(MONTH_ADDR,0);
      delay(t_blink);
      read_date.digits[3] = 10;
      read_date.digits[4] = 10;
      delay(t_blink);
    break;

    case WRITE_YEAR:
      if (rtc_read_dec(YEAR_ADDR) + up <= 99) {
        rtc_write(YEAR_ADDR,rtc_read_dec(YEAR_ADDR) + up);
        up = 0;
      }
      else {
        rtc_write(YEAR_ADDR, 0);
        up = 0;
      }
      read_year.digits[2] = read_digit(YEAR_ADDR,1);
      read_year.digits[3] = read_digit(YEAR_ADDR,0);
      delay(t_blink);
      read_year.digits[2] = 10;
      read_year.digits[3] = 10;
      delay(t_blink);
    break;

    case WRITE_ALARM1_HOUR:
      read_alarm1.digits[2] = read_digit(AL1_MIN_ADDR,1);
      read_alarm1.digits[3] = read_digit(AL1_MIN_ADDR,0);
      read_alarm1.digits[4] = read_digit(AL1_SEC_ADDR,1);
      if (rtc_read_dec(AL1_HOUR_ADDR) + up <= 23) {
        rtc_write(AL1_HOUR_ADDR,rtc_read_dec(AL1_HOUR_ADDR) + up);
        up = 0;
      }
      else {
        rtc_write(AL1_HOUR_ADDR, 0);
        up = 0;
      }
      read_alarm1.digits[0] = read_digit(AL1_HOUR_ADDR,1);
      read_alarm1.digits[1] = read_digit(AL1_HOUR_ADDR,0);
      delay(t_blink);
      read_alarm1.digits[0] = 10;
      read_alarm1.digits[1] = 10;
      delay(t_blink);
    break;

    case WRITE_ALARM1_MINUTE:
      read_alarm1.digits[0] = read_digit(AL1_HOUR_ADDR,1);
      read_alarm1.digits[1] = read_digit(AL1_HOUR_ADDR,0);
      read_alarm1.digits[4] = read_digit(AL1_SEC_ADDR,1);
      if (rtc_read_dec(AL1_MIN_ADDR) + up <= 59) {
        rtc_write(AL1_MIN_ADDR,rtc_read_dec(AL1_MIN_ADDR) + up);
        up = 0;
      }
      else {
        rtc_write(AL1_MIN_ADDR, 0);
        up = 0;
      }
      read_alarm1.digits[2] = read_digit(AL1_MIN_ADDR,1);
      read_alarm1.digits[3] = read_digit(AL1_MIN_ADDR,0);
      delay(t_blink);
      read_alarm1.digits[2] = 10;
      read_alarm1.digits[3] = 10;
      delay(t_blink);
    break;

    case WRITE_ALARM1_SECOND:
      read_alarm1.digits[0] = read_digit(AL1_HOUR_ADDR,1);
      read_alarm1.digits[1] = read_digit(AL1_HOUR_ADDR,0);
      read_alarm1.digits[2] = read_digit(AL1_MIN_ADDR,1);
      read_alarm1.digits[3] = read_digit(AL1_MIN_ADDR,0);
      if (rtc_read_dec(AL1_SEC_ADDR) + up*10 <= 59) {
        rtc_write(AL1_SEC_ADDR,rtc_read_dec(AL1_SEC_ADDR) + up*10);
        up = 0;
      }
      else {
        rtc_write(AL1_SEC_ADDR, 0);
        up = 0;
      }
      read_alarm1.digits[4] = read_digit(AL1_SEC_ADDR,1);
      delay(t_blink);
      read_alarm1.digits[4] = 10;
      delay(t_blink);
    break;

    case WRITE_ALARM1_STATUS:
      rtc_write(STATUS_ADDR, 0b00000000);
      if (up > 0) {
        rtc_write(CTRL_ADDR, rtc_read(CTRL_ADDR) ^ 0b00000001);
        up = 0;
      }
      if (read_bit(CTRL_ADDR, 0)) {
        read_alarm1_status.digits[2] = 10;
        read_alarm1_status.digits[3] = 11;
        read_alarm1_status.digits[4] = 12;
      }
      else {
        read_alarm1_status.digits[2] = 11;
        read_alarm1_status.digits[3] = 13;
        read_alarm1_status.digits[4] = 13;
      }
      delay(t_blink);
      read_alarm1_status.digits[2] = 10;
      read_alarm1_status.digits[3] = 10;
      read_alarm1_status.digits[4] = 10;
      delay(t_blink);
    break;

    case WRITE_ALARM2_HOUR:
      read_alarm2.digits[2] = read_digit(AL2_MIN_ADDR,1);
      read_alarm2.digits[3] = read_digit(AL2_MIN_ADDR,0);
      if (rtc_read_dec(AL2_HOUR_ADDR) + up <= 23) {
        rtc_write(AL2_HOUR_ADDR,rtc_read_dec(AL2_HOUR_ADDR) + up);
        up = 0;
      }
      else {
        rtc_write(AL2_HOUR_ADDR, 0);
        up = 0;
      }
      read_alarm2.digits[0] = read_digit(AL2_HOUR_ADDR,1);
      read_alarm2.digits[1] = read_digit(AL2_HOUR_ADDR,0);
      delay(t_blink);
      read_alarm2.digits[0] = 10;
      read_alarm2.digits[1] = 10;
      delay(t_blink);
    break;

    case WRITE_ALARM2_MINUTE:
      read_alarm2.digits[0] = read_digit(AL2_HOUR_ADDR,1);
      read_alarm2.digits[1] = read_digit(AL2_HOUR_ADDR,0);
      if (rtc_read_dec(AL2_MIN_ADDR) + up <= 59) {
        rtc_write(AL2_MIN_ADDR,rtc_read_dec(AL2_MIN_ADDR) + up);
        up = 0;
      }
      else {
        rtc_write(AL2_MIN_ADDR, 0);
        up = 0;
      }
      read_alarm2.digits[2] = read_digit(AL2_MIN_ADDR,1);
      read_alarm2.digits[3] = read_digit(AL2_MIN_ADDR,0);
      delay(t_blink);
      read_alarm2.digits[2] = 10;
      read_alarm2.digits[3] = 10;
      delay(t_blink);
    break;

    case WRITE_ALARM2_STATUS:
      rtc_write(STATUS_ADDR, 0b00000000);
      if (up > 0) {
        rtc_write(CTRL_ADDR, rtc_read(CTRL_ADDR) ^ 0b00000010);
        up = 0;
      }
      if (read_bit(CTRL_ADDR, 1)) {
        read_alarm2_status.digits[2] = 10;
        read_alarm2_status.digits[3] = 11;
        read_alarm2_status.digits[4] = 12;
      }
      else {
        read_alarm2_status.digits[2] = 11;
        read_alarm2_status.digits[3] = 13;
        read_alarm2_status.digits[4] = 13;
      }
      delay(t_blink);
      read_alarm2_status.digits[2] = 10;
      read_alarm2_status.digits[3] = 10;
      read_alarm2_status.digits[4] = 10;
      delay(t_blink);
    break;

    case ALARM_TRIGGER:
      rtc_write(STATUS_ADDR, 0b00000000); //Reset alarm flag in RTC
      unsigned int i = 0; //Alarm trigger blink repetitions
      while (i < 30) {
        read_time.digits[0] = read_digit(HOUR_ADDR,1);
        read_time.digits[1] = read_digit(HOUR_ADDR,0);
        read_time.digits[2] = read_digit(MIN_ADDR,1);
        read_time.digits[3] = read_digit(MIN_ADDR,0);
        read_time.digits[4] = read_digit(SEC_ADDR,1);
        PORTE = 0b11111110;
        delay(t_blink); 
        TCNT4 = 0;
        read_time.digits[0] = 10;
        read_time.digits[1] = 10;
        read_time.digits[2] = 10;
        read_time.digits[3] = 10;
        read_time.digits[4] = 10; 
        PORTE = 0b11111111;  
        delay(t_blink); 
        i++;  
      }
      PORTE = 0b11111110;
      sleep_flag = 1;
    break;
  }
}

//Read chip temperature
int temp_read() {
  ADCSRA = 0b11000011;          //Enable ADC, start conversion, disable auto trigger and interrupts disabled, set prescaler to 2
  while (ADCSRA & 0b01000000);  //Wait for conversion to complete
  unsigned int temp_raw = ADCL;
  temp_raw |= (ADCH<<8);
  int temp_real = temp_raw - T_OFFSET;
  if ((temp_real > -100) && (temp_real < 100)) {
    return temp_real;
  }
  else {
    return 0;
  }
}

//Read data from RTC - BCD format
uint8_t rtc_read(uint8_t address) {
  uint8_t data_bcd;
  Wire.beginTransmission(RTC_ADDR);
  Wire.write(address);
  Wire.endTransmission();
  Wire.requestFrom(RTC_ADDR,1);
  if (Wire.available()) {
    data_bcd = Wire.read();
  }
  return data_bcd;
}

//Read data from RTC - DEC format
uint8_t rtc_read_dec(uint8_t address) {
  uint8_t data_bcd = rtc_read(address);
  uint8_t data_dec = (data_bcd / 16 * 10) + (data_bcd % 16);
  return data_dec;
}

//Return single digit from byte recieved from RTC
uint8_t read_digit(uint8_t address, bool byte_half) {
  uint8_t digit = 0;
  if (!byte_half) {
    digit = rtc_read(address) & 0b00001111;
  }
  else {
    digit = (rtc_read(address) >> 4) & 0b00000111;
  }
  if (digit < 10) {
    return digit;
  }
  else return 0;
}

//Read single bit from RTC's register
bool read_bit(uint8_t address, uint8_t bit_position) {
  bool flag_bit = (rtc_read(address) >> bit_position) & 0x01;
  return flag_bit;
}

//Write data to RTC
void rtc_write(uint8_t address, uint8_t value) {
  Wire.beginTransmission(RTC_ADDR);
  Wire.write(address);
  Wire.write((value/10*16) + (value%10)); //Convert decimal to BCD
  Wire.endTransmission();
}
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

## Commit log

2024-03-17 restructurized code with structs
    [Retro_Bubble_LED_Watch.kicad_sch]
2024-03-24 added sleep mode
    [Retro_Bubble_LED_Watch.kicad_sch]
2024-06-29 fixed 2nd alarm
    [Retro_Bubble_LED_Watch.kicad_sch]
2024-06-29 changed energy source to cr2032 battery
    [Retro_Bubble_LED_Watch.kicad_pcb, Retro_Bubble_LED_Watch.kicad_sch]
2024-06-30 first partial layout
    [Retro_Bubble_LED_Watch.kicad_pcb, Retro_Bubble_LED_Watch.kicad_sch]
2024-07-02 new layout
    [Retro_Bubble_LED_Watch.kicad_pcb]
2024-07-02 added socket and display models
    [DIP-14_W7.62mm_SMD_Socket.stp, HP5082-7415.stp, HP5082-7415_with_SMD_Socket_assembly.cfg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]
2024-07-06 final PCB design + gerber + initial models
    [HP5082-7415_with_SMD_Socket_assembly.cfg, Retro_Bubble_LED_Watch.kicad_pcb, Retro_Bubble_LED_Watch.kicad_sch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]
2024-07-06 added PCB renderings
2024-07-07 updated models
    [Retro_Bubble_LED_Watch_PCB.cfg, Retro_Bubble_LED_Watch_assembly.cfg]
2024-07-07 added one strap holder
    [Retro_Bubble_LED_Watch_PCB.cfg, Retro_Bubble_LED_Watch_assembly.cfg]
2024-07-09 finished models
    [Retro_Bubble_LED_Watch.kicad_sch, Retro_Bubble_LED_Watch_PCB.cfg, Retro_Bubble_LED_Watch_assembly.cfg]
2024-07-23 finished rev. 1.0
    [Retro_Bubble_LED_Watch.csv, Retro_Bubble_LED_Watch.kicad_pcb, Retro_Bubble_LED_Watch.kicad_sch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]
2024-10-15 Rev. 1.1
    [HP5082-7415_with_SMD_Socket_assembly.stp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]
